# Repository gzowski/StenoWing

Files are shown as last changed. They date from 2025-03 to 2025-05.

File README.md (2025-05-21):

# StenoWing28 - Rev 2
28 key staggered Stenography keyboard without number row
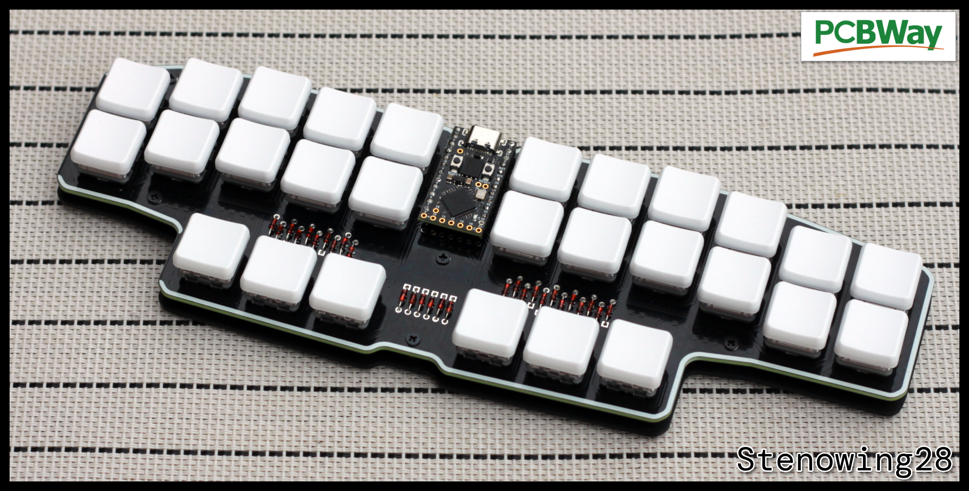
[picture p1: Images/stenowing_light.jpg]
stenowing28

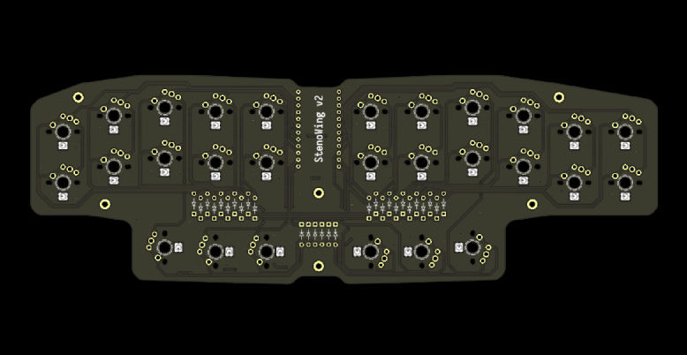
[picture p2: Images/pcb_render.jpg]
stenowing28_pcb

Additional images [here](https://github.com/gzowski/StenoWing/blob/main/Images)

This is now my third keyboard project which has been made possible by the people over at [PCBWay](https://www.pcbway.com) who have sponsored this project and without PCBWay non of these projects would have been possible.

You can find a full writeup on this keyboard project on my website at [Phoenix Boards](https://gzowski.co.uk/?p=230)

The design idea behind this was to follow on from the design of the Ashwing66 while reducing it's footprint further to make something usable for stenography, the intial plan was to retain the wing like design with the 30 degree bend although this was later changed to a more linear layout with a slight vertical stagger.
The bottom row has switches rotated to allow for the use of 1.25U and 1.5U keycaps for those who prefer longer keys.
There are also 28 individually addressable LED's per key.

## Features
* 28 Key layout
* Per key RGB LED's
* Javelin firmware (Reqires RP2040 pro micro with 16MB storage)
* Vertical stagger
* Double tap #2 to change mode and configure RGB

## Parts

| Part | Quantity | Description |
| :--- | :--- | :--- |
| Diodes| 28  | Through-hole 1N4148 |
| Microcontroller | 1 | Pro Micro RP2040 with 16MB Storage |
| Switches | 28 | MX or Choc V1 (67 instead of rotary encoder) |
| Keycaps  | 28 | 1u keycaps |

## Optional Parts

| Part | Quantity | Description |
| :--- | :--- | :--- |
| LED Diodes | 28 |  SK6812 MINI-E |
| Base Plate | 1 | STEP file in 3DPrint folder |
| M2 Standoff | 6 | M2x8mm |
| M2 Screws | 12 | M2x6mm |

##Build Guide

1. Solder the Pro Micro controller to the PCB on the top side, with components facing up
2. Solder the diodes onto the top side of the board, observe orientation.
  - Left side (Black line down), Middle (Black line up), Right (Black line down)
  - Snip off the excess legs from the diodes from the underside once all soldered
3. If using LED's you'll need to place these on the rear side of the PCB, observe the triangle marking on the PCB, this corrosponds to the one leg with an edge cut into it.
  - The LED's are orientated differently on the lowest row due to rotated switches.
4. Insert all switches into the PCB, turn over and solder each switch.
  - Ensure that the switch is seated into the PCB fully before soldering.
5. Place keycaps on top
6. Install desired firmware by putting the controller into BOOT mode.

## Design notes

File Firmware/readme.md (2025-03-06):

# StenoWing

28 key alternative layout

* Keyboard Maintainer: [James Gzowski](https://github.com/gzowski)
* Hardware Supported: Elite-Pi, Frood, 0xB2 Splinky or similar
* Build Guide: [Somei70](https://github.com/gzowski/stenowing)

Make example for this keyboard (after setting up your build environment):
	
    make stenowing:default

Flashing example for this keyboard:

    make stenowing:default:flash

See the [build environment setup](https://docs.qmk.fm/#/getting_started_build_tools) and the [make instructions](https://docs.qmk.fm/#/getting_started_make_guide) for more information. Brand new to QMK? Start with our [Complete Newbs Guide](https://docs.qmk.fm/#/newbs).

## Bootloader

* **Bootmagic reset**: Hold down the key at (0,0) in the matrix (usually the top left key or Escape) and plug in the keyboard
* **Physical reset button**: Briefly press the button on the PCB, if using a RP2040 press repeatidly to enter boot mode.
* **Hold down boot loader button on MCU** Hold down the boot loader button on the MCU while plugging in the keyboard

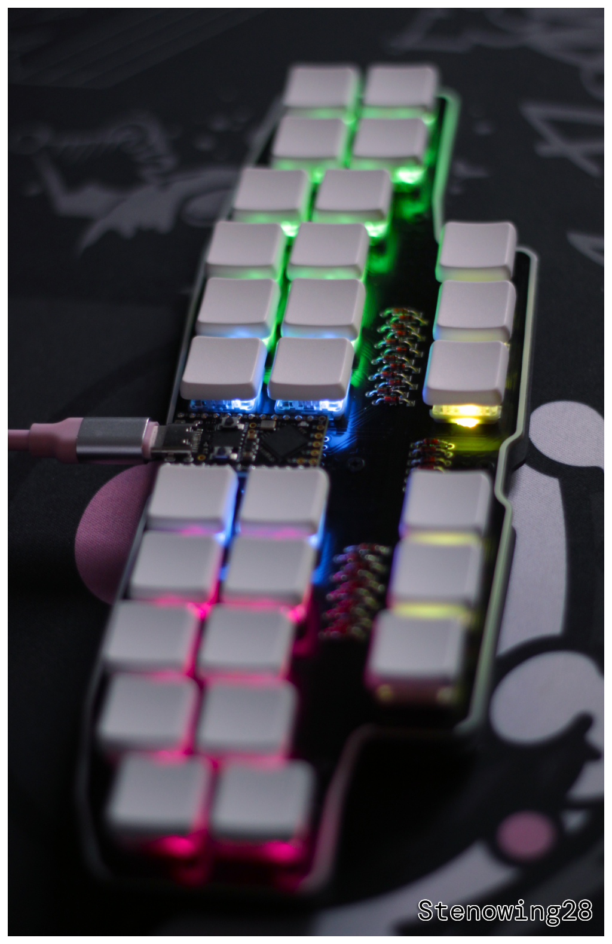
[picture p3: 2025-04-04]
Images/stenowing_dark.jpg

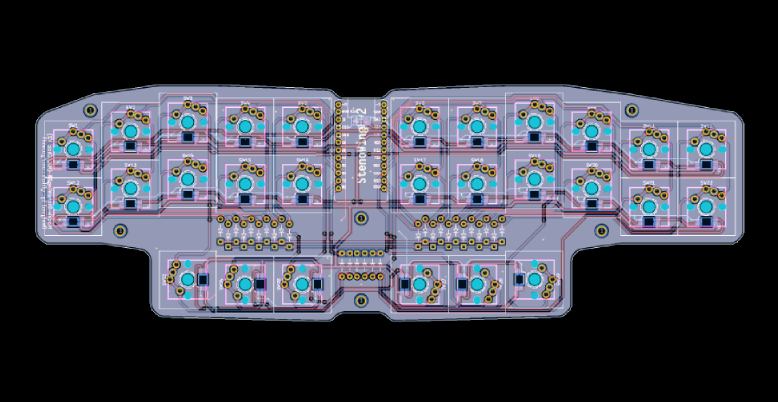
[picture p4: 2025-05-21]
Images/pcb_layout.jpg

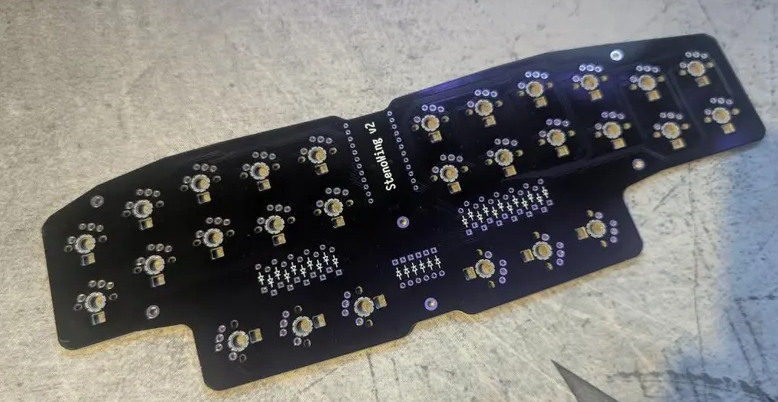
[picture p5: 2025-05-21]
Images/pcb_physical.jpg

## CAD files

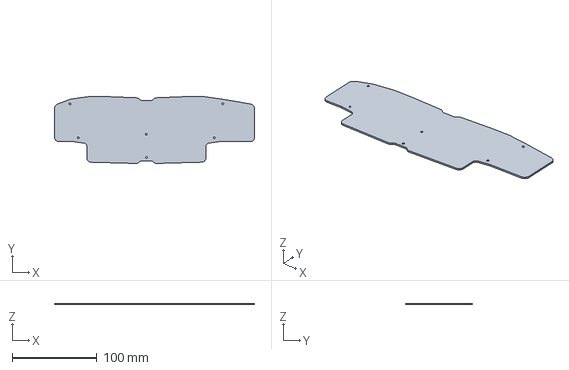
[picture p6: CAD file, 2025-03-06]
3DPlate/StenoWing_plate.step
235.4 x 78.8 x 1.51 mm

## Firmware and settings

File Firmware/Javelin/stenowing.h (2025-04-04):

#pragma once
#include "main_flash_layout.h"

#define JAVELIN_USE_EMBEDDED_STENO 1
#define JAVELIN_USE_USER_DICTIONARY 1
#define JAVELIN_USB_MILLIAMPS 100

#define JAVELIN_DEBOUNCE_MS 10
#define JAVELIN_BUTTON_MATRIX 1

constexpr uint8_t COLUMN_PINS[] = {2, 3, 4, 5, 6, 20, 22, 26, 27, 28, 29};
constexpr uint8_t ROW_PINS[] = {7, 23, 8};
constexpr uint32_t COLUMN_PIN_MASK = 0x3E50007C;
constexpr uint32_t ROW_PIN_MASK = 0x00800180;

constexpr int8_t KEY_MAP[3][16] = {
  {  0,  1,  2,  3,  4, /**/  5,  6,  7,  8,  9, 10 },
  { 11, 12, 13, 14, 15, /**/ 16, 17, 18, 19, 20, 21 },
  { -1, -1, 22, 23, 24, /**/ 25, 26, 27, -1, -1, -1 },
};

#define JAVELIN_RGB 1
#define JAVELIN_RGB_PIN 0
#define JAVELIN_RGB_COUNT 28
#define JAVELIN_USE_RGB_MAP 1

constexpr uint8_t RGB_MAP[JAVELIN_RGB_COUNT] = {
   0, 1, 2, 3, 4, 5, /**/ 6, 7, 8, 9, 10,
  11,12,13,14,15,16, /**/ 17,18,19,20,21,
           22,23,24, /**/ 25,26,27
};

#define JAVELIN_KEYS( \
    S1, TL, PL, HL, ST1, ST3, FR, PR, LR, TR, DR, \
    S2, KL, WL, RL, ST2, ST4, RR, BR, GR, SR, ZR, \
    N1, A, O, E, U, N2 \
) \
{ \
    { S1, TL, PL, HL, ST1, ST3, FR, PR, LR, TR, DR }, \
    { S2, KL, WL, RL, ST2, ST4, RR, BR, GR, SR, ZR }, \
    { N1, A, O, E, U, N2 }  \
}

#define JAVELIN_SCRIPT_CONFIGURATION \
  R"({"name":"StenoWing","layout":[{"x":0,"y":0},{"x":1,"y":0},{"x":2,"y":0},{"x":3,"y":0},{"x":4,"y":0},{"x":5,"y":0},{"x":6,"y":0},{"x":7,"y":0},{"x":8,"y":0},{"x":9,"y":0},{"x":10,"y":0},{"x":0,"y":1},{"x":1,"y":1},{"x":2,"y":1},{"x":3,"y":1},{"x":4,"y":1},{"x":5,"y":1},{"x":6,"y":1},{"x":7,"y":1},{"x":8,"y":1},{"x":9,"y":1},{"x":10,"y":1},{"x":2,"y":2},{"x":3,"y":2},{"x":4,"y":2},{"x":5,"y":2},{"x":6,"y":2},{"x":7,"y":2}]})"

const size_t BUTTON_COUNT = 28;
const char *const MANUFACTURER_NAME = "gzowski";
const char *const PRODUCT_NAME = "StenoWing (Javelin)";
const int VENDOR_ID = 0x31C8;

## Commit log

2025-03-06 Updated, including firmware testing
    [StenoWing.kicad_pcb, StenoWing_plate.kicad_pcb, StenoWing_plate.step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]
2025-04-04 StenoWing V2
    [StenoWing.kicad_pcb, StenoWing_plate.step]
2025-05-21 Added PCBWay logo
